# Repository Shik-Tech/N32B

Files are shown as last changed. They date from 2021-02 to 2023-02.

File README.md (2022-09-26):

# N32B - Midi Controller
N32B Midi controller is an open source hardware and software.
We use the arduino pro micro as the heart of the controller. The N32B is basically an arduino shield and easy to solder project.

You can contribute, build your own or buy a full working device.

You will find the schematics and board layout files in this repository.
Feel free to fork, we would love to see what you created!

# Firmware Repositories
A separate repositories are available for the device firmware variations:

Midi CC firmware:
https://github.com/Shik-Tech/N32B_HiRes

SysEx firmware:
https://github.com/Shik-Tech/N32B-sysEx

## Licensing


Hardware and documentation license is under CC0 1.0 Universal.

Firemware license is under MIT License.

You can find more details about licensing here: https://github.com/Shik-Tech/N32B/blob/master/LICENSE.md

## Additional Information
For more information please visit https://shik.tech

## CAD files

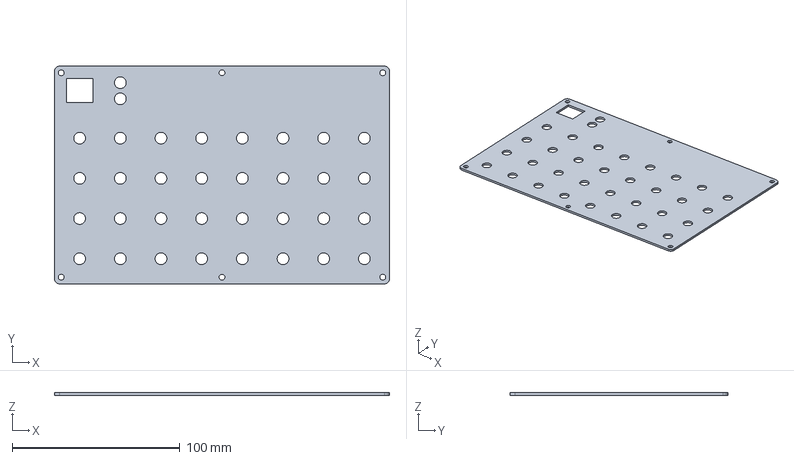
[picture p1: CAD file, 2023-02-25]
Enclosure/Rounded-corners/N32B - Top Panel - Rounded.step
200.0 x 130.0 x 1.50 mm

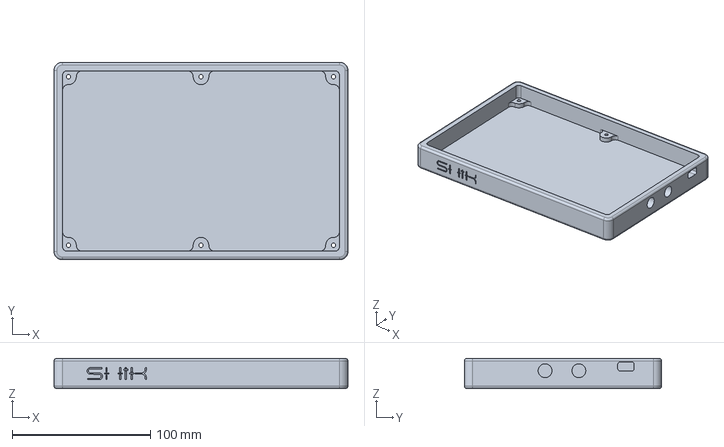
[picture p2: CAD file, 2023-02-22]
Enclosure/Rounded-corners/N32B - Solid Case V10 - Rounded.step
213.0 x 143.0 x 22.0 mm

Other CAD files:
Enclosure/Square-corners/N32B - Top Panel.step
Enclosure/Square-corners/N32B - Solid Case V9.3.step

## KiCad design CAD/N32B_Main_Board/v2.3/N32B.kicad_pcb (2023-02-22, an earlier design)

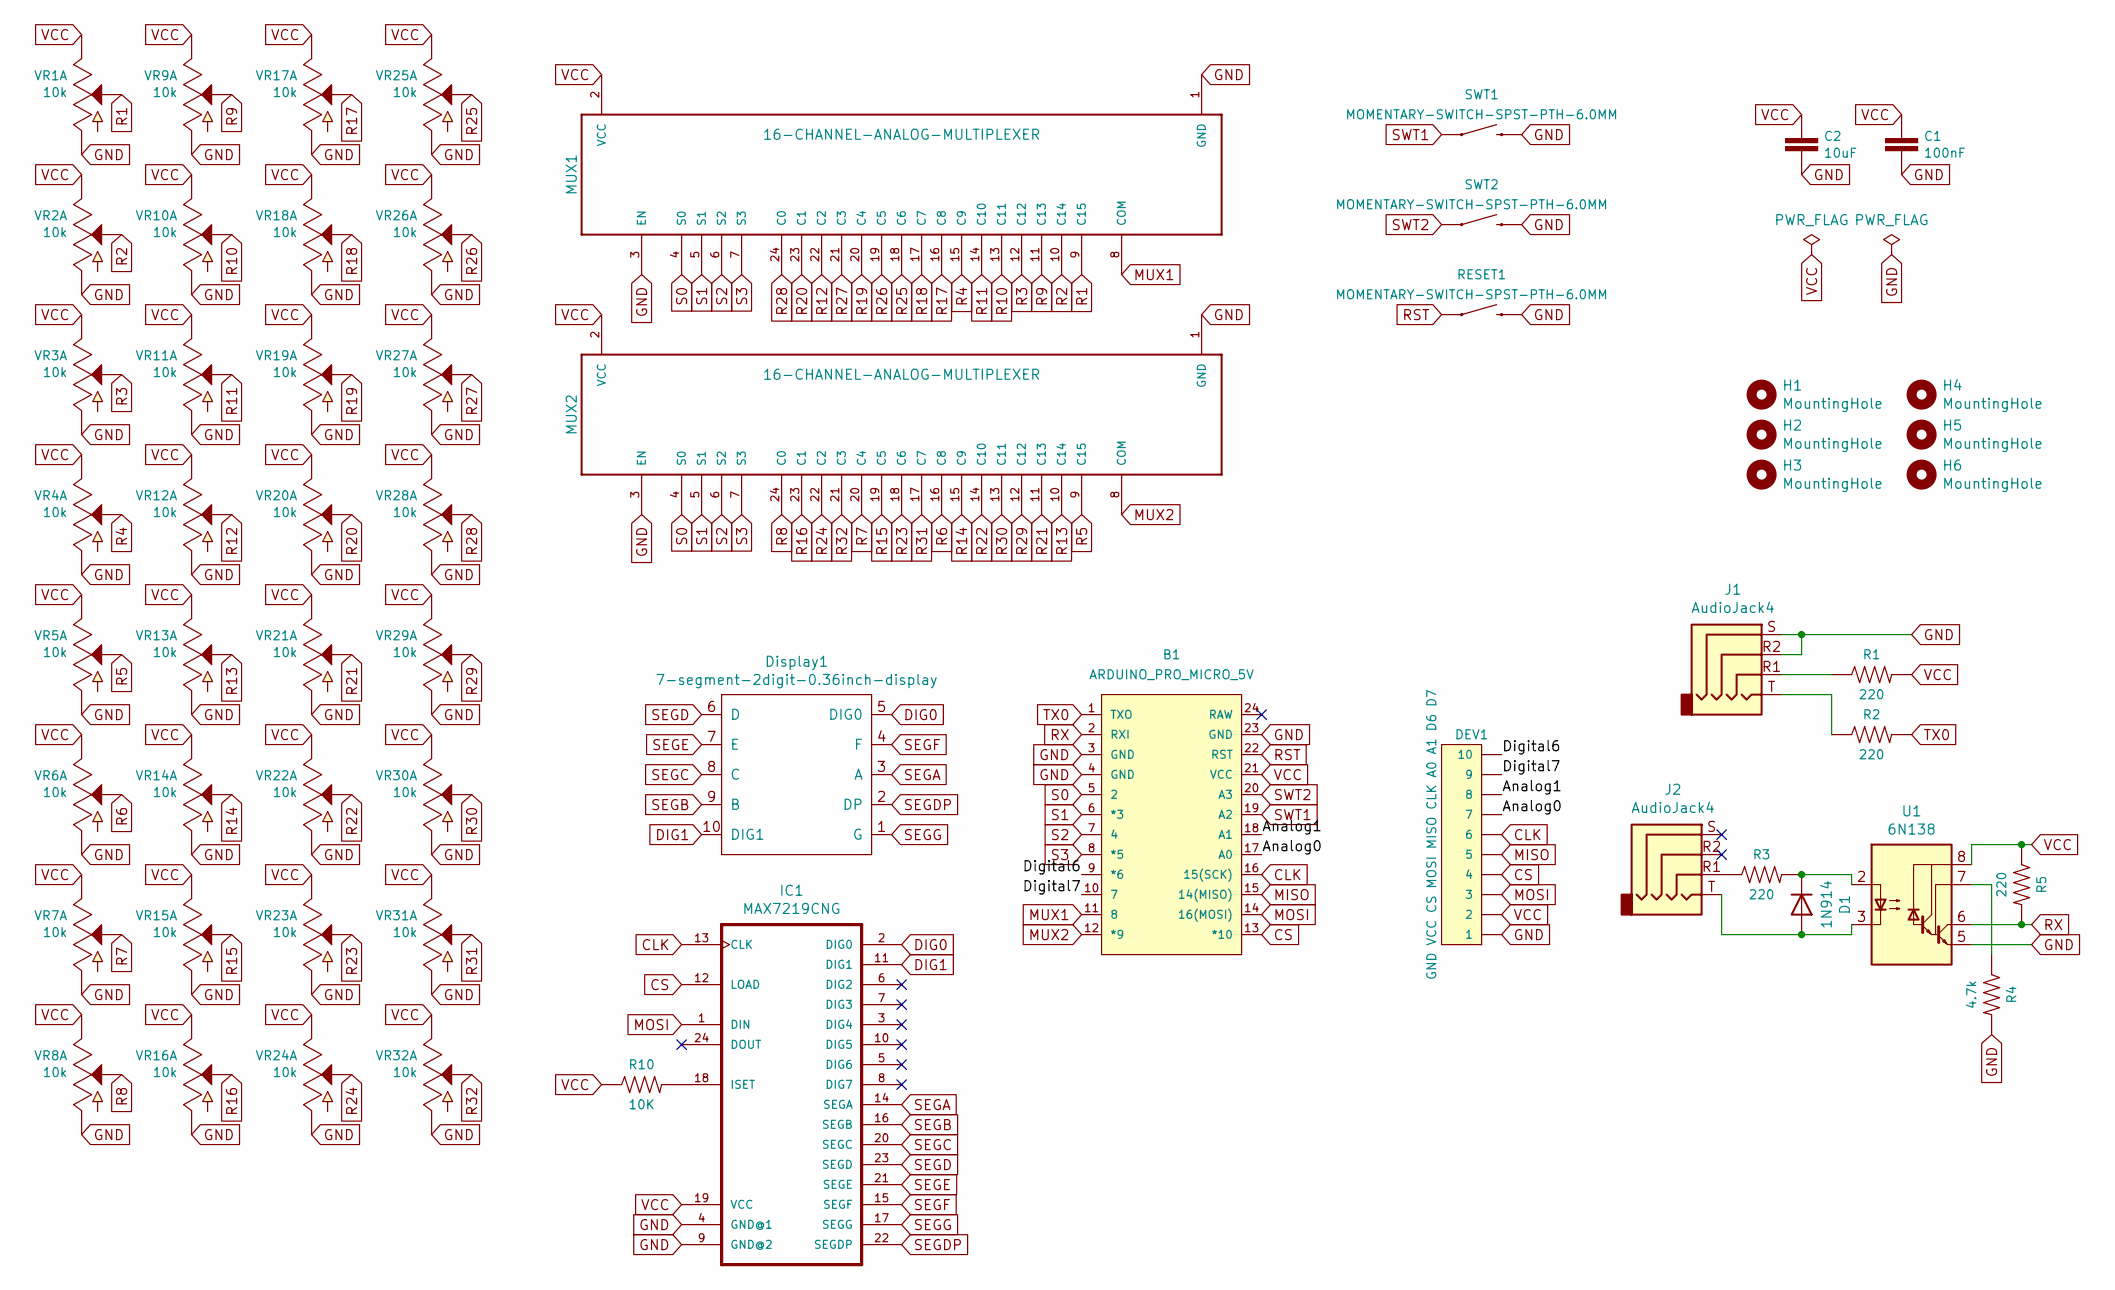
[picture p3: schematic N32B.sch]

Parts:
B1: ARDUINO_PRO_MICRO_5V; ARDUINO_PRO_MICRO
C1: 100nF; CAP-PTH-5.08
C2: 10uF; CAP-PTH-5.08
D1: 1N914; D_DO-35_SOD27_P7.62mm_Horizontal
DEV1: GND VCC CS MOSI MISO CLK A0 A1 D6 D7; PinHeader_2x05_P2.54mm_Vertical
Display1: 7-segment-2digit-0.36inch-display; 7-Segment-2-Digits-0.36inch
H1, H2, H3, H4, H5, H6: MountingHole; MountingHole_3.2mm_M3
IC1: MAX7219CNG; DIL24-3
J1, J2: AudioJack4; Jack_3.5mm_Horizontal
MUX1, MUX2: 16-CHANNEL-ANALOG-MULTIPLEXER; XDCR_BOB-09056
R1, R2, R3, R5: 220; AXIAL-0.3-KIT
R4: 4.7k; AXIAL-0.3-KIT
R10: 10K; AXIAL-0.3-KIT
RESET1: MOMENTARY-SWITCH-SPST-PTH-6.0MM; TACTILE_SWITCH_PTH_6.0MM
SWT1, SWT2: MOMENTARY-SWITCH-SPST-PTH-6.0MM; TACTILE_SWITCH_PTH_6.0MM
U1: 6N138; 6n138
VR1, VR2, VR3, VR4, VR5, VR6, VR7, VR8, VR9, VR10, VR11, VR12, VR13, VR14, VR15, VR16, VR17, VR18, VR19, VR20, VR21, VR22, VR23, VR24, VR25, VR26, VR27, VR28, VR29, VR30, VR31, VR32: 10k; Potentiometer_R09_B103_Single_Vertical

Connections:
/Analog0: B1.17 (A0), DEV1.7
/Analog1: B1.18 (A1), DEV1.8
/Digital6: B1.9 (*6), DEV1.10
/Digital7: B1.10 (7), DEV1.9
CLK: B1.16 (15(SCK)), DEV1.6, IC1.13 (CLK)
CS: B1.13 (*10), DEV1.4, IC1.12 (LOAD)
DIG0: Display1.5 (DIG0), IC1.2 (DIG0)
DIG1: Display1.10 (DIG1), IC1.11 (DIG1)
GND: B1.3 (GND), B1.4 (GND), B1.23 (GND), C1.2, C2.2, DEV1.1, IC1.4 (GND@1), IC1.9 (GND@2), J1.R2, J1.S, MUX1.1 (GND), MUX1.3 (EN), MUX2.1 (GND), MUX2.3 (EN), R4.P$2 (2), RESET1.3 (2), SWT1.3 (2), SWT2.3 (2), U1.5 (GND), VR1.1, VR2.1, VR3.1, VR4.1, VR5.1, VR6.1, VR7.1, VR8.1, VR9.1, VR10.1, VR11.1, VR12.1, VR13.1, VR14.1, VR15.1, VR16.1, VR17.1, VR18.1, VR19.1, VR20.1, VR21.1, VR22.1, VR23.1, VR24.1, VR25.1, VR26.1, VR27.1, VR28.1, VR29.1, VR30.1, VR31.1, VR32.1
MISO: B1.15 (14(MISO)), DEV1.5
MOSI: B1.14 (16(MOSI)), DEV1.3, IC1.1 (DIN)
MUX1: B1.11 (8), MUX1.8 (COM)
MUX2: B1.12 (*9), MUX2.8 (COM)
unnamed: D1.1 (K), R3.P$2 (2), U1.2 (C1)
unnamed: D1.2 (A), J2.T, U1.3 (C2)
unnamed: IC1.18 (ISET), R10.P$2 (2)
unnamed: J1.R1, R1.P$1 (1)
unnamed: J1.T, R2.P$1 (1)
unnamed: J2.R1, R3.P$1 (1)
unnamed: R4.P$1 (1), U1.7 (VO1)
R1: MUX1.9 (C15), VR1.2
R2: MUX1.10 (C14), VR2.2
R3: MUX1.12 (C12), VR3.2
R4: MUX1.15 (C9), VR4.2
R5: MUX2.9 (C15), VR5.2
R6: MUX2.16 (C8), VR6.2
R7: MUX2.20 (C4), VR7.2
R8: MUX2.24 (C0), VR8.2
R9: MUX1.11 (C13), VR9.2
R10: MUX1.13 (C11), VR10.2
R11: MUX1.14 (C10), VR11.2
R12: MUX1.22 (C2), VR12.2
R13: MUX2.10 (C14), VR13.2
R14: MUX2.15 (C9), VR14.2
R15: MUX2.19 (C5), VR15.2
R16: MUX2.23 (C1), VR16.2
R17: MUX1.16 (C8), VR17.2
R18: MUX1.17 (C7), VR18.2
R19: MUX1.20 (C4), VR19.2
R20: MUX1.23 (C1), VR20.2
R21: MUX2.11 (C13), VR21.2
R22: MUX2.14 (C10), VR22.2
R23: MUX2.18 (C6), VR23.2
R24: MUX2.22 (C2), VR24.2
R25: MUX1.18 (C6), VR25.2
R26: MUX1.19 (C5), VR26.2
R27: MUX1.21 (C3), VR27.2
R28: MUX1.24 (C0), VR28.2
R29: MUX2.12 (C12), VR29.2
R30: MUX2.13 (C11), VR30.2
R31: MUX2.17 (C7), VR31.2
R32: MUX2.21 (C3), VR32.2
RST: B1.22 (RST), RESET1.1
RX: B1.2 (RXI), R5.P$2 (2), U1.6 (VO2)
S0: B1.5 (2), MUX1.4 (S0), MUX2.4 (S0)
S1: B1.6 (*3), MUX1.5 (S1), MUX2.5 (S1)
S2: B1.7 (4), MUX1.6 (S2), MUX2.6 (S2)
S3: B1.8 (*5), MUX1.7 (S3), MUX2.7 (S3)
SEGA: Display1.3 (A), IC1.14 (SEGA)
SEGB: Display1.9 (B), IC1.16 (SEGB)
SEGC: Display1.8 (C), IC1.20 (SEGC)
SEGD: Display1.6 (D), IC1.23 (SEGD)
SEGDP: Display1.2 (DP), IC1.22 (SEGDP)
SEGE: Display1.7 (E), IC1.21 (SEGE)
SEGF: Display1.4 (F), IC1.15 (SEGF)
SEGG: Display1.1 (G), IC1.17 (SEGG)
SWT1: B1.19 (A2), SWT1.1
SWT2: B1.20 (A3), SWT2.1
TX0: B1.1 (TXO), R2.P$2 (2)
VCC: B1.21 (VCC), C1.1, C2.1, DEV1.2, IC1.19 (VCC), MUX1.2 (VCC), MUX2.2 (VCC), R1.P$2 (2), R5.P$1 (1), R10.P$1 (1), U1.8 (VCC), VR1.3, VR2.3, VR3.3, VR4.3, VR5.3, VR6.3, VR7.3, VR8.3, VR9.3, VR10.3, VR11.3, VR12.3, VR13.3, VR14.3, VR15.3, VR16.3, VR17.3, VR18.3, VR19.3, VR20.3, VR21.3, VR22.3, VR23.3, VR24.3, VR25.3, VR26.3, VR27.3, VR28.3, VR29.3, VR30.3, VR31.3, VR32.3

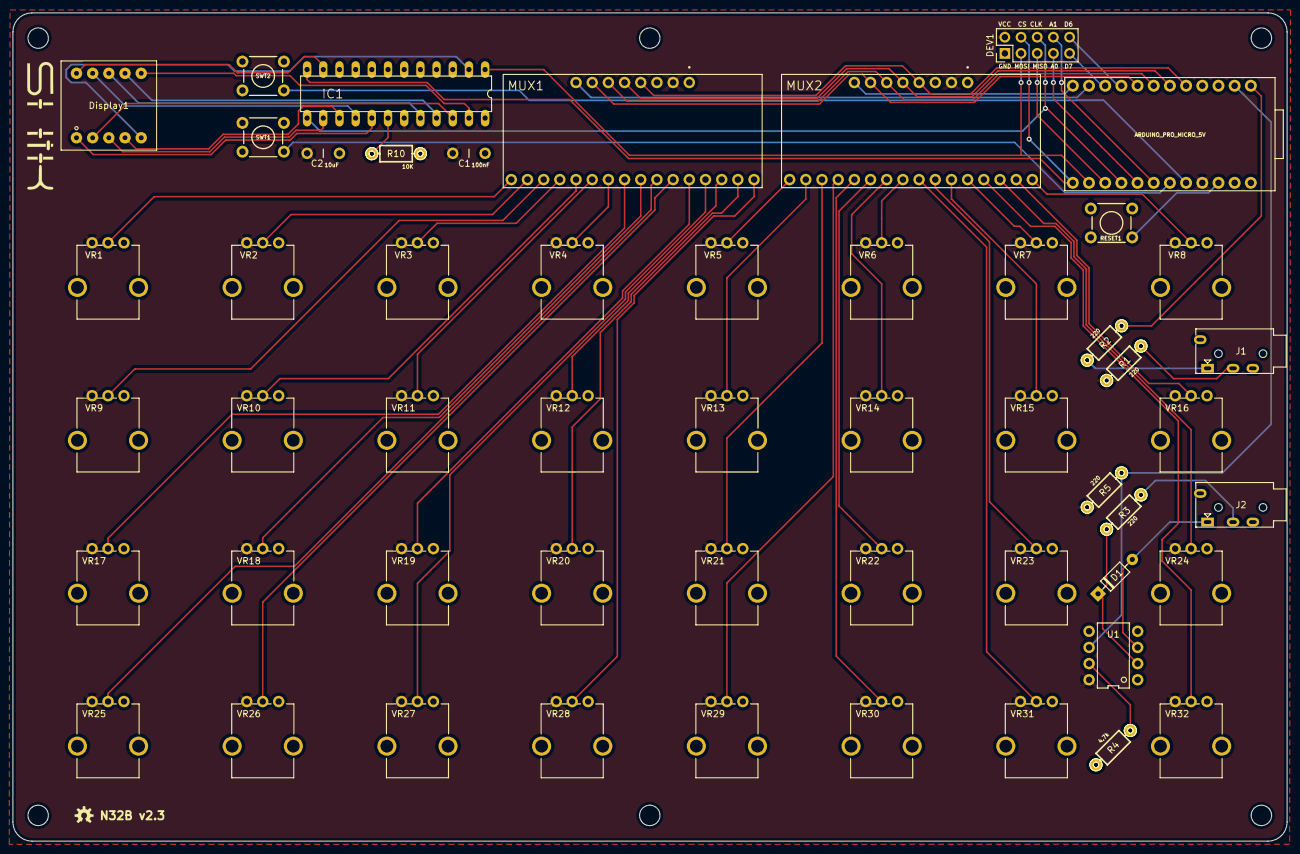
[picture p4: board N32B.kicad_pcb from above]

Board: 2 copper layers, 200.0 x 130.0 mm, 59 parts (0 on the bottom side), 70 nets.

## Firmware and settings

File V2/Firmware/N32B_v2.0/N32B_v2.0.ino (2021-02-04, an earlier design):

/*
  N32B Firmware v2.0
  MIT License

  Copyright (c) 2021 SHIK
*/

/* Libraries */
#include <USB-MIDI.h>
#include <EEPROM.h>
#include <RoxMux.h>
#include <ezButton.h>
#include "DigitLedDisplay.h"

#include "definitions.h"
#include "variables.h"
#include "display.h"

N32B_DISPLAY n32b_display;

/* Mux setup */
#define MUX_TOTAL 2
Rox74HC4067<MUX_TOTAL> mux;

/* Pin setup */
#define MUX_A_SIG 8
#define MUX_B_SIG 9
#define MIDI_TX_PIN 1
#define MUX_S0 2
#define MUX_S1 3
#define MUX_S2 4
#define MUX_S3 5
#define LED_PIN 17
#define BUTTON_A_PIN A3
#define BUTTON_B_PIN A2

ezButton buttonA(BUTTON_A_PIN);
ezButton buttonB(BUTTON_B_PIN);

USING_NAMESPACE_MIDI;

// typedef USBMIDI_NAMESPACE::usbMidiTransport __umt;
// typedef MIDI_NAMESPACE::MidiInterface<__umt> __ss;
// __umt usbMIDI(0); // cableNr
// __ss MIDICoreUSB((__umt &)usbMIDI);

// typedef Message<MIDI_NAMESPACE::DefaultSettings::SysExMaxSize> MidiMessage;
// MIDI_CREATE_INSTANCE(HardwareSerial, Serial1, MIDICoreSerial);
USBMIDI_CREATE_INSTANCE(0, MIDICoreUSB);
MIDI_CREATE_INSTANCE(HardwareSerial, Serial1, MIDICoreSerial);

void setup()
{
  Serial.begin(115200);

  n32b_display.setBright(1);     // Set the display brightness (1-15)
  n32b_display.setDigitLimit(2); // Set amount of digits in the display

  mux.begin(MUX_S0, MUX_S1, MUX_S2, MUX_S3);
  mux.setSignalPin(0, MUX_A_SIG);
  mux.setSignalPin(1, MUX_B_SIG);

  /* Pin setup */
  pinMode(MIDI_TX_PIN, OUTPUT);
  digitalWrite(MIDI_TX_PIN, HIGH); // Prevent random messages on startup
  pinMode(LED_PIN, OUTPUT);
  pinMode(BUTTON_A_PIN, INPUT_PULLUP);
  pinMode(BUTTON_B_PIN, INPUT_PULLUP);
  pinMode(MUX_A_SIG, INPUT);
  pinMode(MUX_B_SIG, INPUT);

  // Set debounce time to 50 milliseconds
  buttonA.setDebounceTime(50);
  buttonB.setDebounceTime(50);

  /*
  * Factory Reset
  * Hold button-A down while powering the device will reset the presets
  */
  if (!digitalRead(BUTTON_A_PIN))
  {
    bool buttonPressed = true;
    digitalWrite(LED_PIN, LOW);

    while (millis() < reset_timeout) // Check if button has been released before timeout
    {
      if (digitalRead(BUTTON_A_PIN))
      {
        buttonPressed = false;
        break;
      }
    }

    // If button is still held down, then clear eeprom
    if (buttonPressed)
    {
      wasFactoryReset = true;
      // Blink once if reset request has been accepted
      digitalWrite(LED_PIN, HIGH);
      delay(20);
      digitalWrite(LED_PIN, LOW);

      // Clean eeprom
      for (int i = 0; i < EEPROM.length(); i++)
      {
        EEPROM.write(i, 0);
      }
      digitalWrite(LED_PIN, HIGH);
    }
  }

  // Write the factory presets to memory if the device was turn on for the first time
  if (!isEEPROMvalid())
  {
    for (uint8_t i = 0; i < 5; i++)
    {
      digitalWrite(LED_PIN, HIGH);
      delay(300);
      digitalWrite(LED_PIN, LOW);
      delay(300);
    }
    formatFactory();
  }

  // Load the last used preset as stored in EEPROM
  loadPreset(EEPROM.read(lastUsedPresetAddress));

  // We don't want any incorrect data sent at startup so we fill the buffers
  for (uint8_t i = 0; i < 32; i++)
  {
    updateKnob(i);                 // Update the buffers
    interpretKnob(i, false, true); // Fill the emission buffers but do not send midi data
  }

  /* Set callbacks */
  MIDICoreUSB.setHandleMessage(onUsbMessage);
  MIDICoreSerial.setHandleMessage(onSerialMessage);

  MIDICoreUSB.setHandleSystemExclusive(processSysex);
  // MIDICoreSerial.setHandleSystemExclusive(processSysex);

  MIDICoreUSB.setHandleProgramChange(handleProgramChange);
  MIDICoreSerial.setHandleProgramChange(handleProgramChange);

  /* Initiate MIDI communications, listen to all channels */
  MIDICoreUSB.begin(MIDI_CHANNEL_OMNI);
  MIDICoreSerial.begin(MIDI_CHANNEL_OMNI);

  MIDICoreUSB.turnThruOn();
  MIDICoreSerial.turnThruOn();

  // Send an Active Sensing MIDI message to notify the target that the controller is on the bus
  MIDICoreUSB.sendRealTime((midi::MidiType)0xFE);
  MIDICoreSerial.sendRealTime((midi::MidiType)0xFE);
}
void onUsbMessage(const MidiInterface<USBMIDI_NAMESPACE::usbMidiTransport>::MidiMessage &message)
{
  MIDICoreSerial.send(message);
}

void onSerialMessage(const MidiInterface<SerialMIDI<HardwareSerial> >::MidiMessage &message)
{
  // MIDICoreUSB.send(message);
  MIDICoreUSB.sendControlChange(message.data1, message.data2, message.channel);
}
// void onUsbMessage(const MidiMessage& message)
// {
//   MIDICoreSerial.send(message);
// }

// void onSerialMessage(const MidiMessage& message)
// {
//   MIDICoreUSB.send(message);
// }

void doMidiRead()
{
  MIDICoreSerial.read();
  MIDICoreUSB.read();
}

void loop()
{
  // Update the multiplexers
  mux.update();

  /* Show factory reset animation */
  if (wasFactoryReset)
  {
    n32b_display.factoryResetAnimation();
    wasFactoryReset = false;
  }

  /* Show startup animation */
  if (wasStartingUp)
  {
    n32b_display.startupAnimation();
    wasStartingUp = false;
  }

  // Iterate all knobs, read update buffers and send
  for (uint8_t currentKnob = 0; currentKnob < 32; currentKnob++)
  {
    doMidiRead();                             // Read
    updateKnob(currentKnob);                  // Update buffers
    doMidiRead();                             // Read
    interpretKnob(currentKnob, false, false); // Send
  }

  n32b_display.renderDisplay(activePreset); // Render the display
  renderFunctionButton();                   // Update buttons stats
}

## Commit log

2021-04-01 Feature/v2.1 (#4)
    * Dynamic memory improvment
    * Display - midi I/O indicator. Reduced active leds.
    * Handle buttons fixes
    * Inhibit msgs when changing channel. Display update
    * Cleanup. Startup animation. Version
    * Fix for NRPN. Cleanup
    * version 2.1 - min/max value support
    * Clean up
    * gitignore update
    [functions.ino, storage.ino, sysex.ino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]
2021-05-03 Support the new mux design in the main board
    [N32B-B_Cu.gbr, N32B-B_Mask.gbr, N32B-B_SilkS.gbr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]
2021-06-06 Update the enclosure files
    [N32B.dxf, N32B.stl]
2021-06-06 Update the top panel stl
    [Top_panel.stl]
2021-07-10 Fixed MIDI IN issue. Added compiled hex file for v3.0.1
    [N32B-B_Cu.gbr, N32B-B_Mask.gbr, N32B-B_SilkS.gbr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]
2021-07-11 Fix for Midi IN
    [functions.ino]
2021-10-25 Hardware updates v2.2
    [N32B-B_Cu.gbl, N32B-B_Mask.gbs, N32B-B_SilkS.gbo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]
2022-09-26 Re-organize hardware versions
    [N32B-B_Cu.gbl, N32B-B_Cu.gbr, N32B-B_Mask.gbr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]
2023-02-22 Adding enclosure files. Cleanup.
    [N32B - Solid Case V10 - Rounded.step, N32B - Solid Case V9.3.step, N32B.kicad_pcb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]
2023-02-22 Sort enclosure files
    [N32B - Solid Case V10 - Rounded.step, N32B - Solid Case V9.3.step]
2023-02-25 Enclosure top panels
    [N32B - Top Panel - Rounded.step, N32B - Top Panel.step]
